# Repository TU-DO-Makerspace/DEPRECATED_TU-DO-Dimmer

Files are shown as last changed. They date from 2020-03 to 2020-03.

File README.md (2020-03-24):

<!-- omit in toc -->
# TU-DO Dimmer

Showcase

A custom DIY RGB dimmer for the TU-DO cafe.

- [Features](#features)
- [Building](#building)
  - [Components](#components)
  - [Perfboard layout](#perfboard-layout)
  - [Configuring, Compiling and flashing the firmware](#configuring-compiling-and-flashing-the-firmware)
- [Usage](#usage)
  - [General usage](#general-usage)
  - [Patch bank](#patch-bank)
    - [Loading/Selecting patches](#loadingselecting-patches)
    - [Saving patches](#saving-patches)
  - [Setting via USB](#setting-via-usb)
    - [Setting RGB only](#setting-rgb-only)
    - [Setting RGB and the main light](#setting-rgb-and-the-main-light)
    - [Retrieving the current color](#retrieving-the-current-color)
- [Documentation](#documentation)

## Features

The TU-DO dimmer can control all three color channels of an RGB LED strip as well as optionally the brightness of a main 12V white LED strip using a set of 4 rotary potentiometers. In addition to satisfying the basic features a lights dimmer, the device also offers a 10-slot patch bank to store light any desired "patches"/configuration. The stored patches may then be loaded. Finally, one last touch that has been added is the option to program the LED strips do a desired HTML color code via USB serial communication.

## Building

### Components

|Component|Quantity|Description|
|---|---|---|
|Arduino Nano|1|The dimmer firmware runs on an Arduino Nano|
|WS2812 Led Strip|1|The WS2812 is the RGB LED strip our choice. The number of "pixels" on the strip must be specified in the [config.h](src/config.h) file. Documentation for non-addressable RGB strips is planned to be added.|
|Main LED Strip|1|The main strip can be any desired LED strip. If no main strip is used, uncomment the `NO_MAIN_STRIP` define directive.|
|Perfboard (At least 31 x 25)|1|Provided the simplicity of this porject, designing a PCB is not planned. A perfboard layout for the dimmer is provided below|
|IRF 630 N-Channel Mosfet|1|The IRF630 is used to drive the main light. Any other N-type MOSFET with the same lead assignments as the IRF 630 can be used in place|
|10k linear potentiometer|4|The potentiometers are used to adjust the lights. 10k pots are recommended, but all linear pots in the 1k to 100k range should work|
|KY-040 Rotary Encoder|1|The rotary encoder is used to switch between- and save patches|
|14,2mm Common Anode 7-Segment display|1|The 7-segment display displays the current patch. Using a common cathode display is possible, but will require `SEV_SEG_COMMON_MODE` to be set to `COMMON_CATHODE` in the [config.h](src/config.h) file.|
|Single row 15 pins 2.54mm female header|2|Two single row 15 pins female headers may be used instead of soldering the Arduino nano directly to the board|
|Single row 5 pins 2.54mm female header|2|Two singlerow 5 pins female headers may be used instead of soldering the 7-segment display directly to the board|

In total the components should be available for less than 25EUR.

All provided components above are based on the perfboard layout below. The project has been written for the Arduino Nano, but will work with little to no change on the Arduino UNO and should be easily portable to other platforms by doing some slight modifications to the firmware. The configuration header in [src/config.h](src/config.h) stores firmware parameters, including pin mappings

### Perfboard layout

Fully assembled (top view):
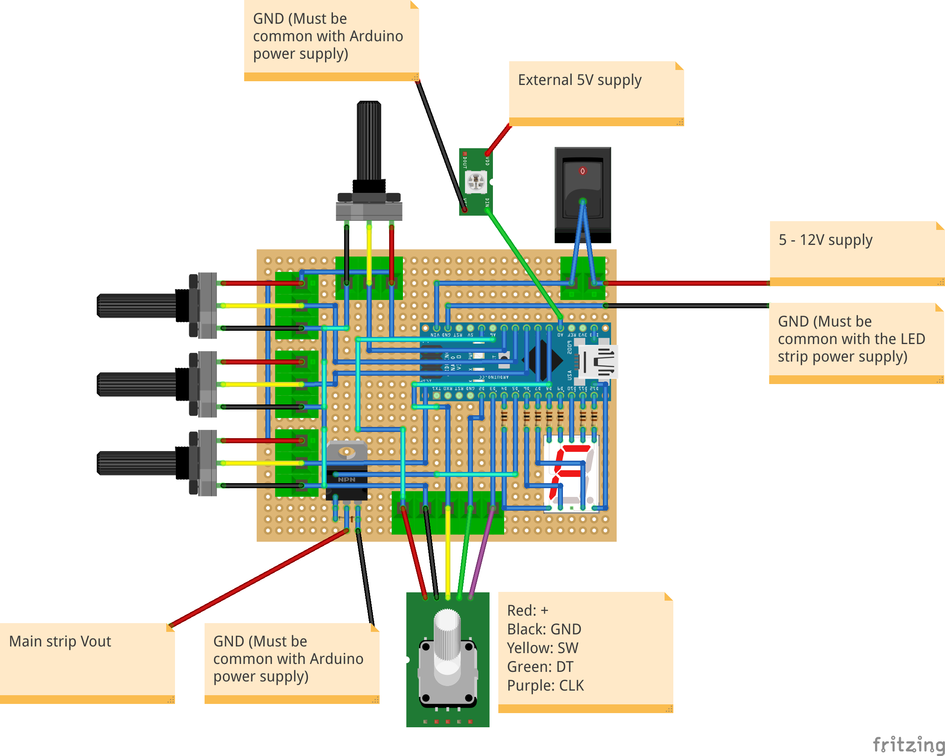
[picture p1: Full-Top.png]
Fully assembled


Terminals, Headers, Resistors and wires only (top view)
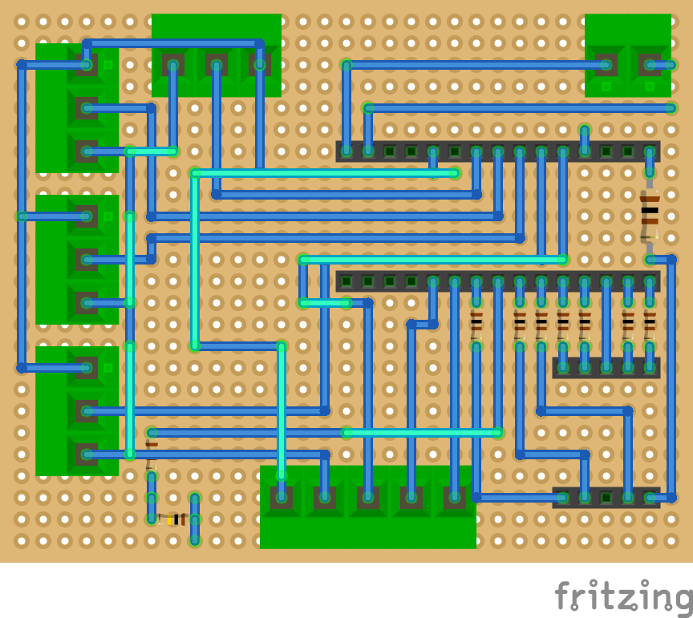
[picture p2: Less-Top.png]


Wires Only with jumpers included (top view)
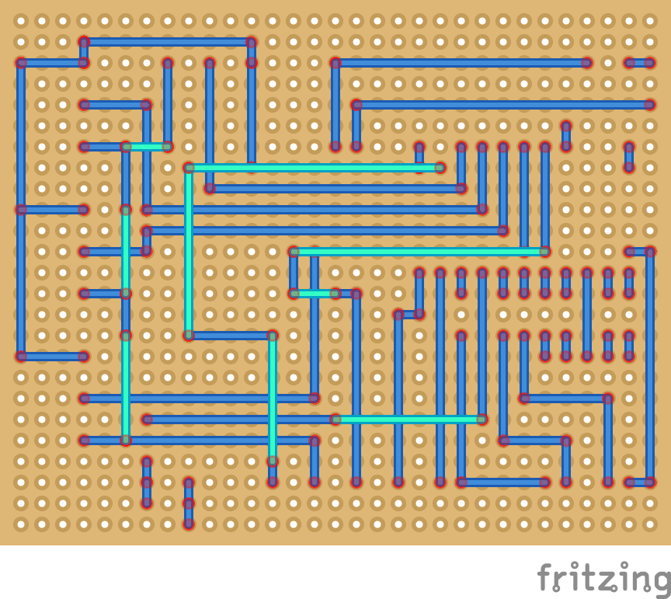
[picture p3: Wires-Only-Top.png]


Bottom wires only (top view)
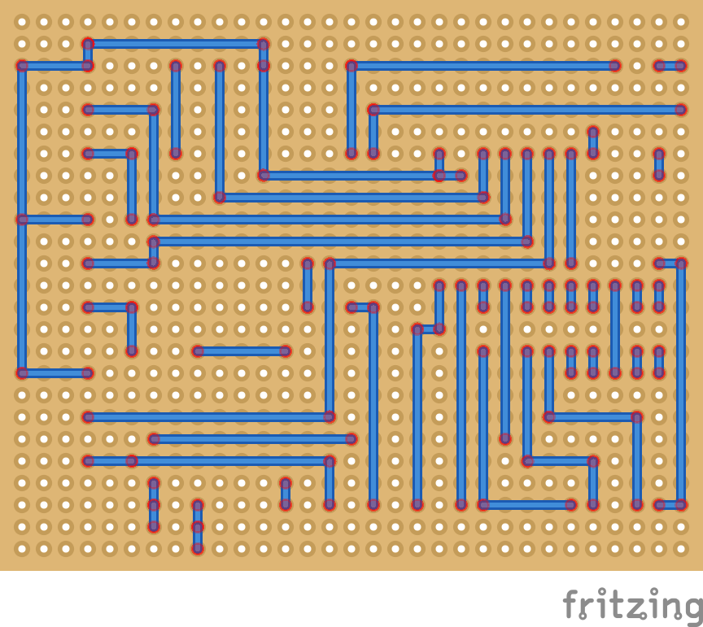
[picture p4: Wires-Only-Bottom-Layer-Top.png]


Bottom wires only (bottom view)
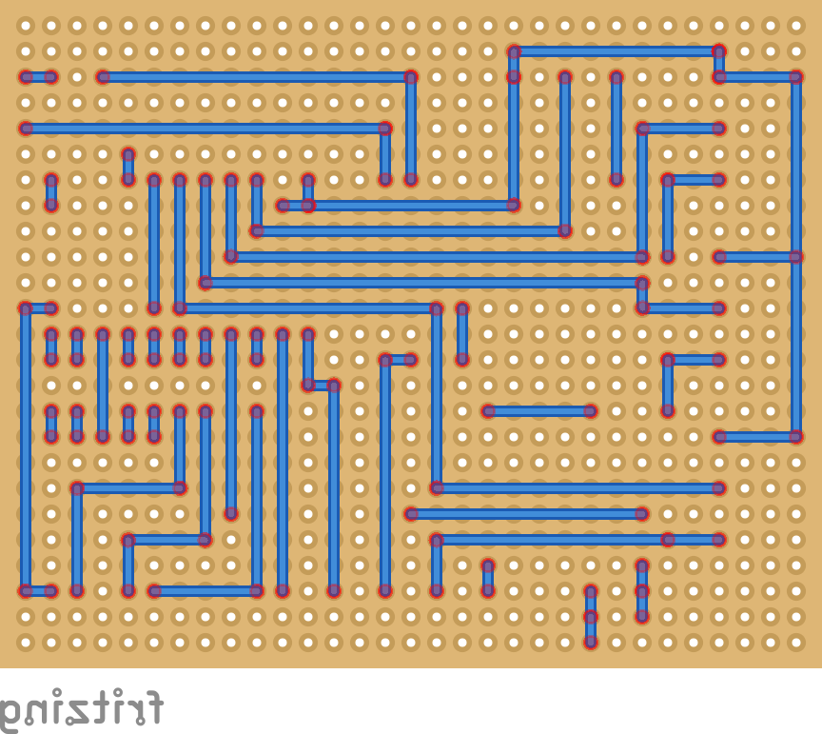
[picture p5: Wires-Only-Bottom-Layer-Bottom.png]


### Configuring, Compiling and flashing the firmware

The following Arduino Libraries are required for the firmware:

- [NeoPixelBus](https://github.com/adafruit/Adafruit_NeoPixel)
- [Paul Stoffregen's encoder library](https://github.com/PaulStoffregen/Encoder)

The firmware has been written using the [Platformio IDE](https://platformio.org/platformio-ide) and can be easily imported from the Platformio home menu.

Alternatively, the source code can be imported into the Arduino IDE. In order to import the project into the Arduino IDE, rename the `src/` directory to `main/` and rename `main.cpp` to `main.ino`. In the Arduino IDE go to `File > Open` and import the `main.ino` file and set the Arduino Nano as the target device.

Before compiling and uploading the firmware, ensure the the firmware parameters in the [config.h](src/config.h) file are configured to your hardware setup (ex. number of LEDs/Pixels on the RGB strip).

## Usage

### General usage

The device offers a total of 4 potentiometers to control the lights, three for the RGB strip and one to control the brightness of the white main light.

### Patch bank

A total of 10 save slots are provided to permanently store a desired light patch/configuration. **Upon device boot, the first (0th) patch is always loaded.**

#### Loading/Selecting patches

Loading the next or previous patch is achieved using a rotary encoder. By turning the rotary encoder to the right, the next patch is loaded, contrary, turning it to the left will select the previous patch. When a new patch has been selected, the patch is applied to the lights and the 7-Segment LED indicator will display the currently selected save slot for a brief time. As soon as the potentiometers are turned, the loaded configuration is discarded and the LEDs are once again set by the potentiometer values.

#### Saving patches

To save the current lights configuration to the currently selected save slot, press down the rotary encoder. The 7-Segment patch indicator will flash the currently selected save slot, confirming that the current patch has been saved.

### Setting via USB

As mentioned above, the lights may also be programmed via USB serial communication by providing a HTML color code.

#### Setting RGB only

To only program the RGB lights, a typical HTML/Hex color code in the form of `#AABBCC` is send via the Serial console.

Example, setting the RGB strip to red:
```
#FF000
```

The hex characters are case insensitive and the preceding `#` sign must be provided!

#### Setting RGB and the main light

Should one desire to also set the brightness of the main light, an additional byte (two hex character) is added to the HTML color code, controlling the brightness.

Example, disabling RGB lights and setting the Main light to full brightness:
```
#000000FF
```

Once again, the hex characters are case insensitive and the preceding `#` sign must be provided!

The light will maintain their programmed value until potentiometer movement is detected.

#### Retrieving the current color

One may also retrieve information regarding the current lights configuration by simply sending the `g` command via the serial console.

Example:
```
g
Current Color: #AABBCCDD
R: 170
G: 187
B: 204
M: 221
```

## Documentation

TUDO :)

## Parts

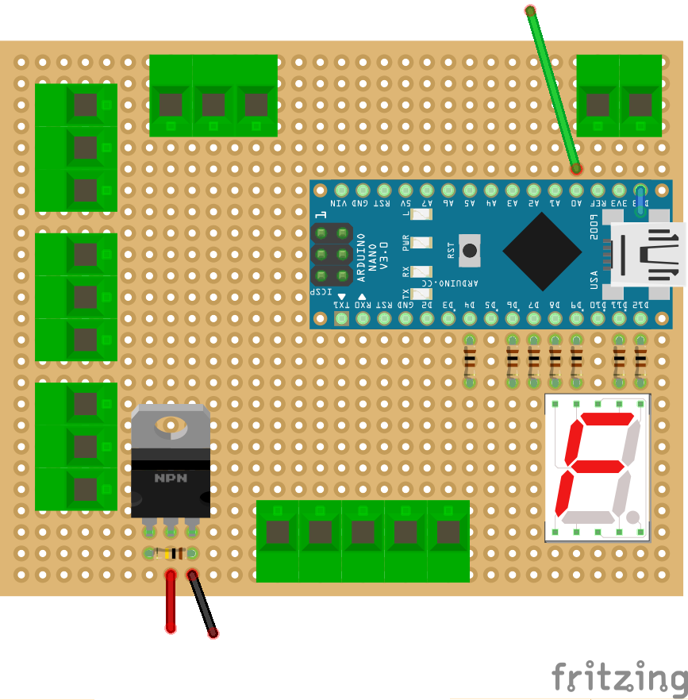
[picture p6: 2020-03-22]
Components-Only-Top.png

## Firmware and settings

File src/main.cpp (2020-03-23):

  /*
   * Copyright (C) 2020  Patrick Pedersen, The TU-DO Makespace

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
   * Author: Patrick Pedersen <ctx.xda@gmail.com>
   * Description: Main firmware routines for our custom TU-DO Makespace Cafe lights dimmer
   * 
   */

#include <math.h>

#include <Arduino.h>
#include <EEPROM.h>
#include <NeoPixelBus.h> // https://github.com/Makuna/NeoPixelBus

#include "config.h"
#include "LEDStrip.h"
#include "credits.h"
#include "PatchIndicator.h"
#include "PatchEncoder.h"

#ifndef __AVR__
#error Sorry, only AVR boards are currently supported
#endif

#define ANALOG_READ_MAX 1023

#define RGB_HEX_STR_LEN  7 // #AABBCC
#define RGBM_HEX_STR_LEN 9 // #AABBCCDD

//////////////////////////////
// Structs
//////////////////////////////

/* rgbm
 * ----
 * Description: 
 *      A simple struct to store RGB and Main light values.
 *      RGB values are provided as Neopixel RgbColor object
 *      (See https://github.com/Makuna/NeoPixelBus/wiki/RgbColor-object-API).
 */

struct rgbm {
        RgbColor rgb;
        uint8_t M;
};

//////////////////////////////
// Functions
//////////////////////////////

/* uint32_pow
 * ----------
 * Arguments:
 *      base - 8-bit base
 *      pow - 8-bit Power/Exponent
 * Returns:
 *      A 32 bit result of base^pow
 * Description:
 *      Returns a 32 bit result of base^pow
 */

inline uint32_t uint32_pow(uint8_t base, uint8_t pow)
{
        uint32_t ret = 1;

        for (uint8_t i = 0; i < pow; i++)
        ret *= base;

        return ret;
}

/* adc_to_rgb
 * ----------
 * Arguments:
 *      val - A 16 bit analogRead() return
 * Returns:
 *      val >> 2 (= val/4)
 * Description:
 *      Reduces analogRead() values to a byte (0-255)
 */

inline uint8_t adc_to_rgb(uint16_t val)
{
        if (val == 0)
                return 0;
        else if (val < 4)
                return 1;

        return (val >> 2);
}

/* avg_pot_read
 * ----------
 * Arguments:
 *      pin - Pin of Potentiometer
 *      samples - Number of read samples to be averaged
 * Returns:
 *      8-bit average
 * Description:
 *      Reads an 8-bit average value of n potentiometer read samples.
 */

inline uint8_t avg_pot_read(uint8_t pin, uint16_t samples)
{
        uint64_t avg = 0;

        for (uint16_t i = 0; i < samples; i++)

#ifdef POTS_INVERTED
                avg += ANALOG_READ_MAX - analogRead(pin);
#else
                avg += analogRead(pin);
#endif

        return adc_to_rgb(round(avg/samples));
}

/* rgbm_pots_read
 * ----------
 * Arguments:
 *      pot_r - Pin of red potentiometer
 *      pot_g - Pin of green potentiometer
 *      pot_b - Pin of blue potentiometer
 *      pot_m - Pin of main lights potentiometer
 * Returns:
 *      rgbm object of potentiometer values
 * Description:
 *      Returns the current red, green, blue and mains light potentiometer values to an rgbm object
 */

inline rgbm rgbm_pots_read(uint8_t pot_r, uint8_t pot_g, uint8_t pot_b, uint8_t pot_m)
{
        rgbm ret;

#ifdef POTS_INVERTED
        ret.rgb.R = adc_to_rgb(ANALOG_READ_MAX - analogRead(R_POT));
        ret.rgb.G = adc_to_rgb(ANALOG_READ_MAX - analogRead(G_POT));
        ret.rgb.B = adc_to_rgb(ANALOG_READ_MAX - analogRead(B_POT));
        ret.M = adc_to_rgb(ANALOG_READ_MAX - analogRead(M_POT));
#else
        ret.rgb.R = adc_to_rgb(analogRead(R_POT));
        ret.rgb.G = adc_to_rgb(analogRead(G_POT));
        ret.rgb.B = adc_to_rgb(analogRead(B_POT));
        ret.M = adc_to_rgb(analogRead(M_POT));
#endif

#if R_POT_LOWER_BOUND > 0
        if (ret.rgb.R <= R_POT_LOWER_BOUND)
                ret.rgb.R = 0;
#endif

#if G_POT_LOWER_BOUND > 0
        if (ret.rgb.G <= G_POT_LOWER_BOUND)
                ret.rgb.G = 0;
#endif

#if B_POT_LOWER_BOUND > 0
        if (ret.rgb.B <= B_POT_LOWER_BOUND)
                ret.rgb.B = 0;
#endif

#if M_POT_LOWER_BOUND > 0
        if (ret.M <= M_POT_LOWER_BOUND)
                ret.M = 0;
#endif

        return ret;
}

/* avg_rgbm_pot_read
 * ----------
 * Arguments:
 *      pot_r - Pin of red potentiometer
 *      pot_g - Pin of green potentiometer
 *      pot_b - Pin of blue potentiometer
 *      pot_m - Pin of main lights potentiometer
 *      samples - Potentiometer read samples to be averaged
 * Returns:
 *      rgbm object of average potentiometer values
 * Description:
 *      Returns the current red, green, blue and mains light potentiometer values to an rgbm object
 */

inline rgbm avg_rgbm_pot_read(uint8_t pot_r, uint8_t pot_g, uint8_t pot_b, uint8_t pot_m, uint16_t samples)
{
        rgbm ret;

        ret.rgb.R = avg_pot_read(pot_r, samples);
        ret.rgb.G = avg_pot_read(pot_g, samples);
        ret.rgb.B = avg_pot_read(pot_b, samples);
        ret.M = avg_pot_read(pot_m, samples);
        
        return ret;
}

/* rgbm_pot_mov_det
 * ----------
 * Arguments:
 *      rgbmpots - rgbm object with current potentiometer values
 *      avg - rgbm object with average potentiometer values 
 *      max_dev - Max deviation from average (max_dev = |current pots value - avg|)
 * Returns:
 *      True - Potentiometer movement detected (Pot value exceeded the maximum deviation from the average)
 *      False - No significant potentiometer movement detected 
 * Description:
 *      Detects between noise and real potentiometer movement.
 *      Returns true if significant potentiometer movement has been detected.
 */

inline bool rgbm_pot_mov_det(rgbm rgbmpots, rgbm avg, uint8_t max_dev)
{
        return (
                abs(rgbmpots.rgb.R - avg.rgb.R) > max_dev ||
                abs(rgbmpots.rgb.G - avg.rgb.G) > max_dev ||
                abs(rgbmpots.rgb.B - avg.rgb.B) > max_dev
#ifndef NO_MAIN_STRIP
                || abs(rgbmpots.M - avg.M) > max_dev
#endif
        );
}

//////////////////////////////
// Global vars & Objects
//////////////////////////////

// LED Strips
uint8_t mainstrp_bright; // Current brightness of main light strip

#if RGB_STRIP_TYPE == ADDRESSABLE
RGBStrip rgbstrp(RGB_STRIP_LEDS, RGB_STRIP);
#else
RGBStrip rgbstrp(RGB_STRIP_R, RGB_STRIP_G, RGB_STRIP_B);
#endif

rgbm rgbmpots; // Stores current potentiometer values
rgbm avg; // Stores average potentiometer values

rgbm patches[10]; // Patches/Slots of RGBM configurations
uint8_t current_patch; // Currently selected patch

// Rotary Encoder
PatchEncoder patch_encoder(ROTARY_ENC_DT, ROTARY_ENC_CLK, ROTARY_ENC_SW, ROTARY_ENC_DEBOUCE_TIME);

// 7 Segment patch indicator
PatchIndicator patch_indicator (
        SEV_SEG_COMMON_MODE, 
        SEV_SEG_COMMON,
        SEV_SEG_A, 
        SEV_SEG_B, 
        SEV_SEG_C, 
        SEV_SEG_D, 
        SEV_SEG_E, 
        SEV_SEG_F, 
        SEV_SEG_G,
        SEV_SEG_DP
);

// External color programming

// When set to true, the device will maintain its current color
// until potentiometer movement is detected
bool programmed = false;

///////////////////////
// Color via serial
///////////////////////

/* print_rgbm
 * ----------
 * Arguments:
 *      rgbm - rgbm object to be printed
 * Description:
 *      Prints rgbm values to the serial console 
 */

void print_rgbm(rgbm rgbm)
{
        String rgb_hex[4] { String(rgbm.rgb.R, HEX), String(rgbm.rgb.G, HEX), String(rgbm.rgb.B, HEX), String(rgbm.M, HEX)};

        for (uint8_t i = 0; i < 4; i++) {
                if (rgb_hex[i].length() == 1)
                        rgb_hex[i] = "0" + rgb_hex[i];
        }

        Serial.println("Current Color: #" + rgb_hex[0] + rgb_hex[1] + rgb_hex[2] + rgb_hex[3]);
        Serial.println("R: " + String(rgbm.rgb.R));
        Serial.println("G: " + String(rgbm.rgb.G));
        Serial.println("B: " + String(rgbm.rgb.B));
        Serial.println("M: " + String(rgbm.M));
}

/* hexstr_to_uint32
 * ----------
 * Arguments:
 *      *_hex - A return pointer to a uint32_t 
 *      hexstr - A string of hex characters (without 0x prefix)
 * Returns:
 *      True - hex string has successfully been converted to uin32_t
 *      False - Invalid hex character found 
 * Description:
 *      Converts a hex string without prefixes ("0x" etc.) to
 *      a 32 bit value uint32_t. If an invalid hex has been provided,
 *      false is returned.
 */

bool hexstr_to_uint32(String hexstr, uint32_t *_hex)
{
        uint32_t hex = 0;

        for (size_t i = 0; i < hexstr.length(); i++) {
                if (hexstr[i] >= '0' && hexstr[i] <= '9')
                        hex += (hexstr[i] - 0x30) * uint32_pow(16, (hexstr.length() - 1 - i));
                else if (hexstr[i] >= 'A' && hexstr[i] <= 'F')
                        hex += (hexstr[i] - 55) * uint32_pow(16, (hexstr.length() - 1 - i));
                else if (hexstr[i] >= 'a' && hexstr[i] <= 'f')
                        hex += (hexstr[i] - 87) * uint32_pow(16, (hexstr.length() - 1 - i));
                else
                        return false;
        }

        *_hex = hex;
        return true;
}

/* hexstr_to_rgb
 * ----------
 * Arguments:
 *      hex - A rgb hex string (ex. #AABBCC) 
 *      rgb - RgbColor return pointer 
 * Returns:
 *      True - hex string has successfully been parsed to RgbColor object
 *      False - Invalid hex string
 * Description:
 *      Parses a RGB hex string (frequently known as html color codes)
 *      to a NeoPixel RgbColor object. If an invalid hex code is provided,
 *      false is returned.
 */

bool hexstr_to_rgb(String hex, RgbColor *rgb)
{
        uint32_t rgb_hex;
        bool valid;

        if (hex[0] != '#')
                return false;

        valid = hexstr_to_uint32(hex.substring(1, RGB_HEX_STR_LEN), &rgb_hex);
        
        if (valid)
                *rgb = HtmlColor(rgb_hex);
        
        return valid;
}

/* hexstr_to_rgbm
 * ----------
 * Arguments:
 *      hex - A rgbm hex string (ex. #AABBCCDD) 
 *      rgbn - rgbm return pointer 
 * Returns:
 *      True - hex string has successfully been parsed to rgbm object
 *      False - Invalid hex string
 * Description:
 *      Parses a RGBM hex string to a rgbm object. If an invalid hex
 *      code is provided,, false is returned.
 */
bool hexstr_to_rgbm(String hex, rgbm *rgbm)
{
        RgbColor rgb;
        uint32_t m;

        String rgb_hex;
        String m_hex;

        if (hex[0] != '#')
                return false;

        rgb_hex = hex.substring(0, RGB_HEX_STR_LEN);

        if (!hexstr_to_rgb(rgb_hex, &rgb))
                return false;
        
        rgbm->rgb = rgb;
        
        m_hex = hex.substring(RGB_HEX_STR_LEN, RGBM_HEX_STR_LEN);
        
        if (!hexstr_to_uint32(m_hex, &m))
                return false;

        rgbm->M = m;
        return true;
}

/*
 * serialEvent
 * -----------
 * Description:
 *      Processes incoming serial communication:
 *      - When the 'g' command is received, the current color information is emitted
 *      - When a RGB html value (ex. #AABBCC) is received, the RGB strip is programmed to that color
 *      - When a RGBM (RGBA) html value is received (ex. #AABBCCDD), the RGB strip and main light is programmed to that value.
 *        The main light strip brightness is controlled by the last two hex numbers.
 */

void serialEvent()
{
        static String cmdbuf = "";
        while(Serial.available()) {
                char c = (char)Serial.read();

                switch (c) {
                        case 'g': {
                                rgbm rgbm = {
                                        rgbstrp.get(), 
                                        mainstrp_bright
                                };
                                
                                print_rgbm(rgbm);
                                cmdbuf = "";
                                break;
                        }
                        case '\a': {
                                RgbColor prev_color = rgbstrp.get();
                                authors_credit(&rgbstrp);
                                rgbstrp.set(prev_color);
                                cmdbuf = "";
                                break;
                        }
                        case '\n': {
                                bool valid = false;

                                if (cmdbuf.length() == RGB_HEX_STR_LEN) {
                                        RgbColor rgb;
                                        valid = hexstr_to_rgb(cmdbuf, &rgb);

                                        if (valid) {
                                                rgbstrp.set(rgb);
                                        }
                                                
                                } else if (cmdbuf.length() == RGBM_HEX_STR_LEN) {
                                        rgbm rgbm;
                                        valid = hexstr_to_rgbm(cmdbuf, &rgbm);
  
                                        if (valid) {
                                                rgbstrp.set(rgbm.rgb);
#ifndef NO_MAIN_STRIP
                                                mainstrp_bright = rgbm.M;
                                                analogWrite(MAIN_STRIP, mainstrp_bright);
#endif
                                        }
                                }
                                
                                if (valid) {
                                        // Read average of pots for potentiometer movement detection 
                                        avg = avg_rgbm_pot_read(R_POT, G_POT, B_POT, M_POT, POT_MOV_DET_AVG_SAMPLES);
                                        programmed = true;
                                } else {
                                        Serial.println("Invalid hex value!");
                                }

                                cmdbuf = "";
                                break;
                        }
                        default: {
                                cmdbuf += c;
                                break;
                        }
                }
        }
}

//////////////////////////////
// Rotary Encoder Interrupts
//////////////////////////////

/* change_patch
 * ------------
 * Parameters:
 *      up - If set true, the next patch is selected, if 
 *           set false, the previous patch is selected
 * Description:
 *      Changes the patch to the next or previous one
 */

void change_patch(bool up)
{
        bool invalid = false;

        if (up && current_patch < 9)
                current_patch++;
        else if (!up && current_patch > 0)
                current_patch--;
        else
                invalid = true;
  
        if (!invalid) {
                rgbstrp.set(patches[current_patch].rgb);
#ifndef NO_MAIN_STRIP
                mainstrp_bright = patches[current_patch].M;
                analogWrite(MAIN_STRIP, mainstrp_bright);
#endif
                avg = avg_rgbm_pot_read(R_POT, G_POT, B_POT, M_POT, POT_MOV_DET_AVG_SAMPLES);
                programmed = true;
                patch_indicator.set(current_patch);
        }

        patch_indicator.show(PATCH_DISPLAY_TIME);
}

/* patch_up
 * --------
 * Description:
 *      Selects next patch. This function is triggered
 *      by clock-wise rotary encoder movement.
 */

void patch_up()
{
        change_patch(true);
}

/* patch_up
 * --------
 * Description:
 *      Selects previous patch. This function is triggered
 *      by counter-clockwise rotary encoder movement.
 */

void patch_dwn()
{
        change_patch(false);
}

/* save_patch
 * --------
 * Description:
 *      Saves current RGB and main light patch to the patch bank.
 *      This function is triggered by pressing the rotary encoder.
 */

void save_patch()
{
        patches[current_patch].rgb = rgbstrp.get();
        patches[current_patch].M = mainstrp_bright;
        EEPROM.put(EEPROM_PATCH_ADDR + (sizeof(rgbm) * current_patch), patches[current_patch]);
        patch_indicator.blink(NUM_SAVE_BLINKS, BLINK_INTERVAL_ON, BLINK_INTERVAL_OFF);
}


//////////////////////////////
// Initialization
//////////////////////////////

/* setup
 * -----
 * Description:
 *      - Sets the potentiometer pin modes to INPUT
 *      - Sets the main light strip pin mode to OUTPUT
 *      - Prints the boot message (provided in config.h)
 *      - Loads the patches from the EEPROM
 *      - Initializes the RGB light strip from the values of the 0th patch
 *      - Initializes the main light strip from the values of the 0th patch
 *      - Initializes the 7 segment patch indicator
 *      - Initializes the rotary encoder
 */

void setup()
{
#ifdef NO_MAIN_STRIP
        pinMode(M_POT, INPUT_PULLUP);
#else
        pinMode(M_POT, INPUT);
#endif
        pinMode(R_POT, INPUT);
        pinMode(G_POT, INPUT);
        pinMode(B_POT, INPUT);

        pinMode(MAIN_STRIP, OUTPUT);

        Serial.begin(9600);
        Serial.println(String(BOOT_MSG_ASCII_ART) + "\n");
        Serial.println("Author(s): " + String(BOOT_MSG_AUTHORS));
        Serial.println("License: " + String(BOOT_MSG_LICENSE));
        Serial.println("Build date: " + String(__DATE__));
        Serial.println("Documentation: " + String(BOOT_MSG_SRC));

        // Load patches from EEPROM into ram
        EEPROM.get(EEPROM_PATCH_ADDR, patches);

        // Load 0th patch on boot
        current_patch = 0;

        rgbstrp.set(patches[current_patch].rgb);
#ifndef NO_MAIN_STRIP
        mainstrp_bright = patches[current_patch].M;
        analogWrite(MAIN_STRIP, mainstrp_bright); // Sets the brightness of the mainstrip
#endif

        // 7-Segment Initialization
        patch_indicator.set(0);
        patch_indicator.show(PATCH_DISPLAY_TIME);

        avg = avg_rgbm_pot_read(R_POT, G_POT, B_POT, M_POT, POT_MOV_DET_AVG_SAMPLES);
        programmed = true;
}

//////////////////////////////
// Main loop
//////////////////////////////

/*
 * loop
 * -----
 * Description:
 *      The main loop of the dimmer firmware.
 * 
 *       - Read the values of the RGB and main light potentiometers
 *       - Checks if the light has been programmed (ex. by loading a patch or by applying a html code).
 *         If programmed, the RGB and main light are only changed if potentiometer movement is detected.
 *       - RGB light and main lights are set according to the potentiometers
 *       - The rotary encoder is tested
 *       - The patch indicator is updated/handled
 * 
 *       Avoid implementing time intensive instructions/operations, as any delays
 *       will reduce the smoothness of the color transitions.
 */

void loop()
{
        rgbmpots = rgbm_pots_read(R_POT, G_POT, B_POT, M_POT);

        if (!programmed || rgbm_pot_mov_det(rgbmpots, avg, POT_MOV_DET_MAX_DEV)) {
                rgbstrp.set(rgbmpots.rgb); // Set RGB strip
#ifndef NO_MAIN_STRIP
                mainstrp_bright = rgbmpots.M;
                analogWrite(MAIN_STRIP, mainstrp_bright); // Set main light strip
#endif
                programmed = false;
        }

        switch (patch_encoder.action()) {
                case pressed:
                        save_patch();
                        break;
                case left:
                        change_patch(false);
                        break;
                case right:
                        change_patch(true);
                        break;
                default:
                        break;
        }

        if (patch_indicator.busy())
                patch_indicator.update();
}

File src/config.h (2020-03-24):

  /*
   * Copyright (C) 2020  Patrick Pedersen, The TU-DO Makespace

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
   * Author: Patrick Pedersen <ctx.xda@gmail.com>
   * Description: Configuration file for the TU-DO custom light dimmer firmware
   * 
   */

#pragma once

#include "PatchIndicator.h"

///////////////////////////
// Hardware Parameters
///////////////////////////

/* Pots */
#define R_POT A4
#define G_POT A3
#define B_POT A2
#define M_POT A5 // Main light

/* Rotary encoder */
#define ROTARY_ENC_DT  2 // INT 0
#define ROTARY_ENC_CLK 3 // INT 1
#define ROTARY_ENC_SW  A0

/* LED Strips */
// #define NO_MAIN_STRIP // No main LED strip present,
                         // defining this will prevent noise from toggling potentiometer movement detection
#define MAIN_STRIP     5

// Addressable Strips (NeoPixel/WS2812)
#define RGB_STRIP_TYPE ADDRESSABLE
#define RGB_STRIP      A1
#define RGB_STRIP_LEDS 30 // Number of LEDs/Pixels on the RGB strip

// Non-Addressable Strips (Replace XX with free PWM pins)
// #define RGB_STRIP_TYPE NON_ADDRESSABLE
// #define RGB_STRIP_A    XX
// #define RGB_STRIP_G    XX
// #define RGB_STRIP_B    XX

/* 7-Segment Patch Indicator */
#define SEV_SEG_COMMON_MODE COMMON_ANODE
#define SEV_SEG_A      11
#define SEV_SEG_B      12
#define SEV_SEG_C      7
#define SEV_SEG_D      6
#define SEV_SEG_E      4
#define SEV_SEG_F      9
#define SEV_SEG_G      8
#define SEV_SEG_DP     13
#define SEV_SEG_COMMON 10

///////////////////////////
// Firmware parameters
///////////////////////////

/* Rotary Encoder */
#define ROTARY_ENC_DEBOUCE_TIME 250

/* Potentiometers */
#define POT_MOV_DET_AVG_SAMPLES 100
#define POT_MOV_DET_MAX_DEV     6
// #define POTS_INVERTED // Inverts the potentiometer readings in case of wiring screw ups...

// Lower bounds
// When pot values are less and equal to the lower bound, 
// the color channel is disabled. This serves to compensate
// for flickering caused by potentiometer noise.
#define R_POT_LOWER_BOUND 0
#define G_POT_LOWER_BOUND 0
#define B_POT_LOWER_BOUND 0
#define M_POT_LOWER_BOUND 0

/* 7-Segment Patch Indicator */
#define NUM_SAVE_BLINKS    3
#define BLINK_INTERVAL_ON  250  // ms
#define BLINK_INTERVAL_OFF 250  // ms
#define PATCH_DISPLAY_TIME 5000 // Time (ms) for 7-seg to remain on after changing patches

/* Patches */
#define EEPROM_PATCH_ADDR  0x0 // Start of patches array in EEPROM

/* Boot message */
#define BOOT_MSG_AUTHORS "Patrick Pedersen <ctx.xda@gmail.com>"
#define BOOT_MSG_LICENSE "GPLv3"
#define BOOT_MSG_SRC "https://github.com/TU-DO-Makerspace/TU-DO-Disco"
#define BOOT_MSG_ASCII_ART \
"Created by the:\n"\
"\n"\
" ______   __  __\n"\
"/\\__  _\\ /\\ \\/\\ \\\n"\
"\\/_/\\ \\/ \\ \\ \\_\\ \\\n"\
"   \\ \\_\\  \\ \\_____\\\n"\
"    \\/_/   \\/_____/\n"\
"\n"\                    
" _____     ______\n"\    
"/\\  __-.  /\\  __ \\\n"\   
"\\ \\ \\/\\ \\ \\ \\ \\/\\ \\\n"\  
" \\ \\____-  \\ \\_____\\\n"\ 
"  \\/____/   \\/_____/\n"\
"\n"\
"\n"\
"Makerspace | Do it yourself!"

/* Authors Credit */
#define MORSE_SHORT 200
#define MORSE_LONG 3 * MORSE_SHORT
#define MORSE_BTWN MORSE_SHORT
#define MORSE_LETTER MORSE_LONG

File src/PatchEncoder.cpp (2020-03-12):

#include "PatchEncoder.h"

PatchEncoder::PatchEncoder()
{

}

PatchEncoder::PatchEncoder(uint8_t dt, uint8_t clk, uint8_t sw, unsigned long debounce_time) : _debounce_time(debounce_time)
{
        _debounce = false;
        _sw = PushButton(sw, true);
        _rotary_enc = new Encoder(dt, clk);
        _pos = _rotary_enc->read();
}

PatchEncoder::~PatchEncoder()
{
        delete _rotary_enc;
        _rotary_enc = NULL;
}

encoder_action PatchEncoder::action()
{
        if (_debounce && millis() >= _debounce_tstamp) {
                encoder_action ret = no_action;
                _debounce = false;

                long read = _rotary_enc->read();
                
                if (read > _pos)
                        ret = right;
                else if (read < _pos)
                        ret = left;

                _pos = read;

                return ret;
        } else if (!_debounce && _rotary_enc->read() != _pos) {
                _debounce = true;
                _debounce_tstamp = millis() + _debounce_time;
        } else if (_sw.released()) {
                return pressed;
        }

        return no_action;
}

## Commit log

2020-03-04 First prototype firmware
2020-03-06 Replaced push buttons with KY040 Rotary encoder
    [main.cpp]
2020-03-08 Main: adc_to_rgb: Fixed indentation
    [main.cpp]
2020-03-08 Main: Replaced rgbstrp_color with rgbstrp.GetPixelColor(0)
    [main.cpp]
2020-03-08 Main: Fixed RGBM programming via serial
    [main.cpp]
2020-03-10 Added firtizing sketch for perf
    [Perfboard.fzz]
2020-03-10 Perfboard: Added terminals for on/off switch
    [Perfboard.fzz]
2020-03-12 Build: Compile for arduino nano
2020-03-12 RotaryEncoder: Changed lib for faster encoder registration
2020-03-12 Config: Set Rotary encoder debounce time to 50ms
2020-03-13 Config: Set number of LEDs/Pixels to 30
2020-03-20 PatchIndicator: Updated pin out + Disabled decimal point
2020-03-22 README: Added hardware documentation
    [Perfboard.fzz]
2020-03-23 Main: Fixed false potentiometer movement positives
    [main.cpp]
2020-03-23 Added support for non-addressable LED Strips
2020-03-24 Config: Increased rotary encoder debounce time to 250ms

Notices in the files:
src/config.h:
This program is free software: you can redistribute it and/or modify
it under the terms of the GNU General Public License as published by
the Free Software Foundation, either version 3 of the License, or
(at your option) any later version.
